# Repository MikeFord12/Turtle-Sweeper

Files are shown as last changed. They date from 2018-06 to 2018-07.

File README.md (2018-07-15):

# Turtle-Sweeper

# Background

This repository holds the code for the turtle sweeper team's GVSU final project. Code for each module, libraries, and then main logic code are included.

The purpose of this project is to provide a solution for tracking neonate (newborn) turtles in their natural wooded habitat that is more cost-effective than the current method. RFID technology can provide an inexpensive option to do this. The low cost of the tags will enable more neonates to be tracked at once, which given their high mortality rate, will provide better data on their migratory habits. RFID was also chosen due to the availability of long-lasting tags. Passive RFID tags can last years, while active VHF tags run out of battery life in about a month.

The goal is to design an easy to use system that can easily find and identify turtles, as well as keep track of their movement through seamless data logging. In order to be able to easily identify the turtles in the wild the Ultra High-Frequency range was chosen due to its longer read ranges. An Arduino Mega 2560 was selected as the microcontroller interface with the ThingMagic M6E Nano reader shield. To achieve higher gain and external antenna was added.  A 6mm passive RFID tag was selected, and based on Fiis Transmission estimations, the tag will read at the 10” ranges in free space and in dry conditions.

The UI was designed using modules compatible with the Arduino microcontroller to include event saving functionality, GPS location, LCD display, battery level indication, and keeping time. The mechanical design was inspired by a metal detector wand. The metal detector design will increase the reach of the user and place the antenna closer to the specimen. Overall this design will improve the ability to control the antenna and improve its portability. The increased portability will enable the user to cover more ground and search in areas that might be difficult to reach. 

# Setup

If anyone desires to clone and run this code, the included libraries must be present in the user’s Arduino IDE. The Arduino IDE used for development is Version 1.8.5. The SD, SoftwareSerial, and SPI libraries used are included in the Arduino IDE. The external libraries used are included in the Github repo. 

---------------------------------------------------------------------
**In order for these to work you must put these library folders in your “arduino->libraries” directory. If there is no libraries folder in your arduino directory, you must create one and put the library folders inside of there.**
---------------------------------------------------------------------

# Contact

For questions about this repository you can contact:  
Mike Ford – fordmich@mail.gvsu.edu  
David Bizzocchi – bizzoccd@mail.gvsu.edu

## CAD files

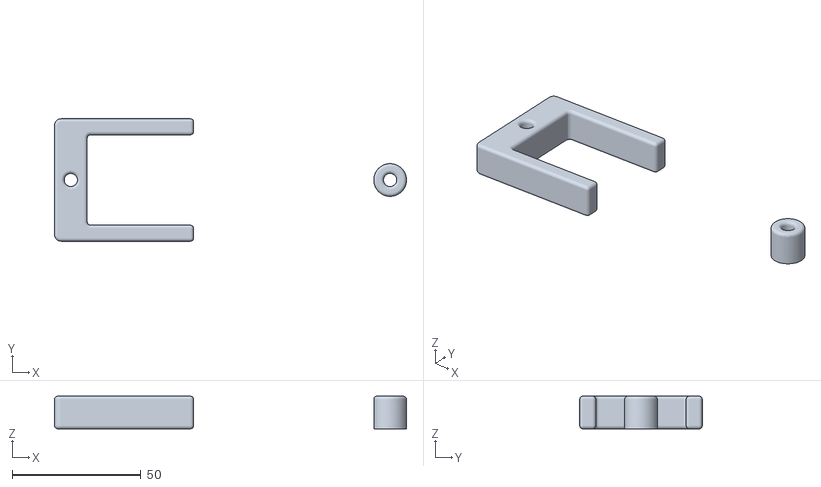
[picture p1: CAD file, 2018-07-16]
3D prints/Battery Holder Size Reducer.STL
136.5 x 47.5 x 12.7

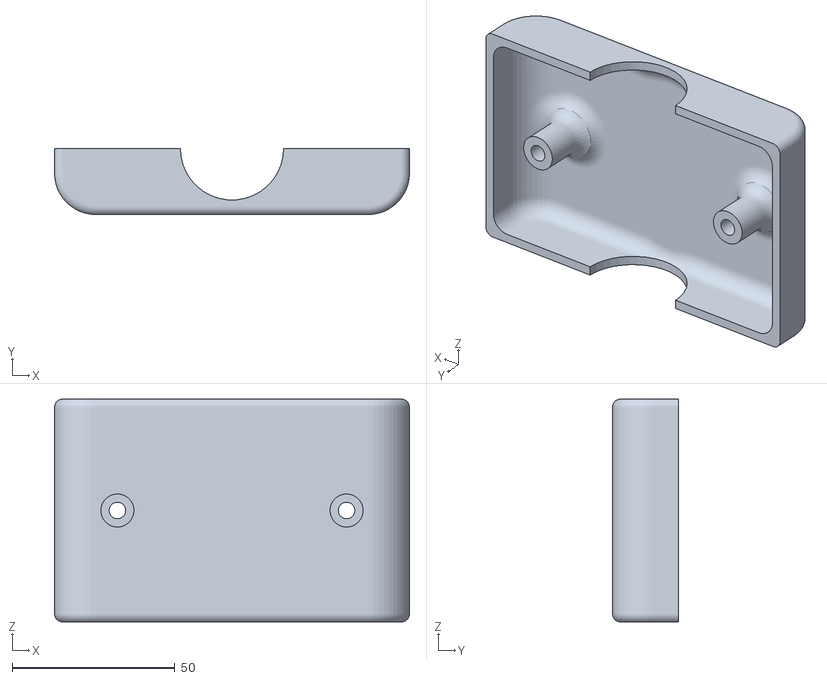
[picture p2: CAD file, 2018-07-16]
3D prints/Bracket_CASE_COVER.STL
109.2 x 20.3 x 68.6

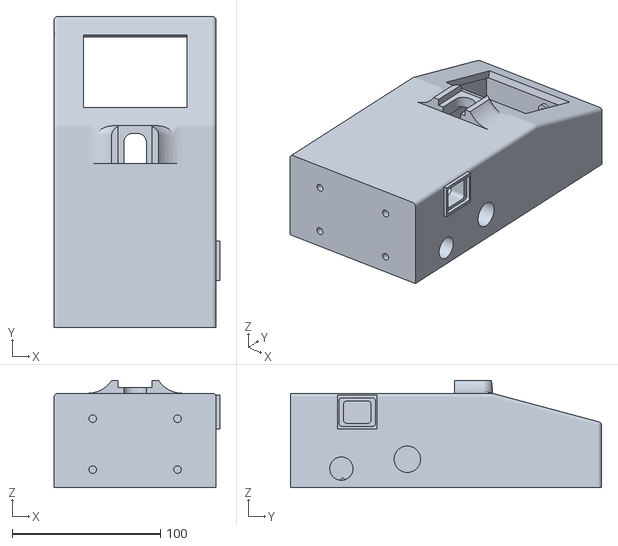
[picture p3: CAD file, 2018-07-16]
3D prints/Handle_V3_SIDE_A.STL
111.8 x 209.6 x 72.1

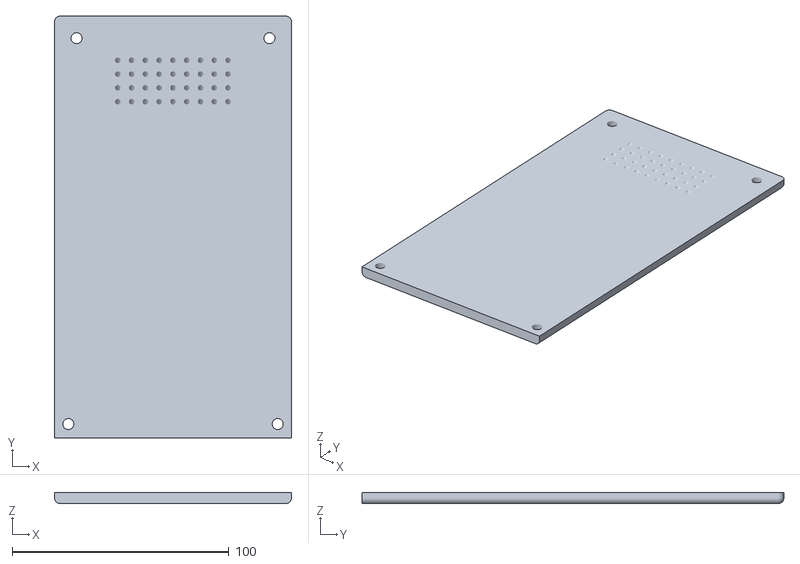
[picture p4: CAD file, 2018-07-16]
3D prints/LCD_BackPlate_V3.STL
109.2 x 194.3 x 5.08

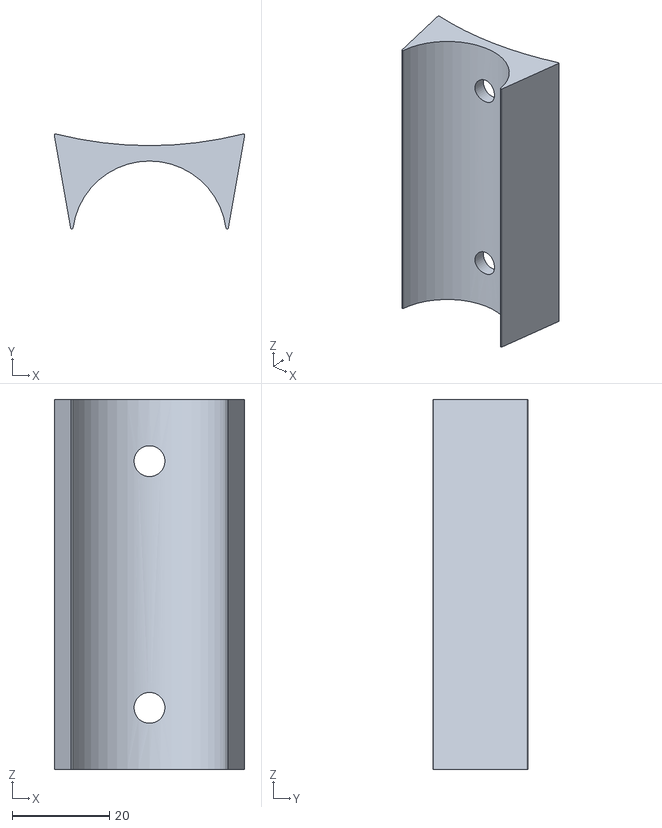
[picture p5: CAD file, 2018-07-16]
3D prints/ArmRest_Adpt.STL
39.2 x 19.6 x 76.2

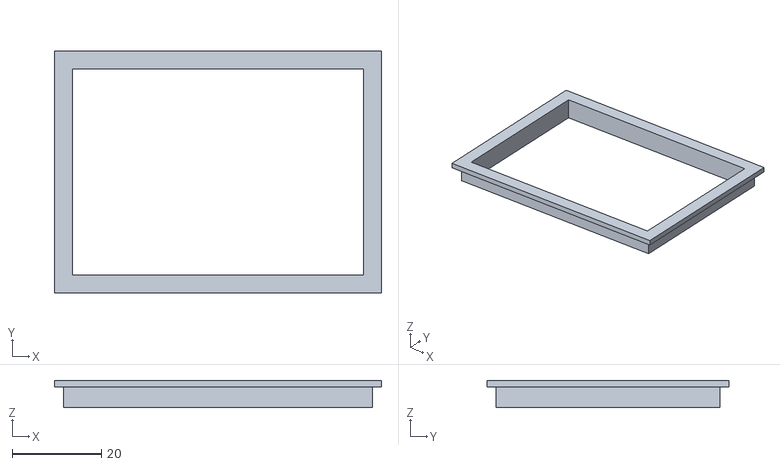
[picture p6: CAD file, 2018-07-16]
3D prints/LCD Screen Gasket.STL
73.5 x 54.3 x 6.07

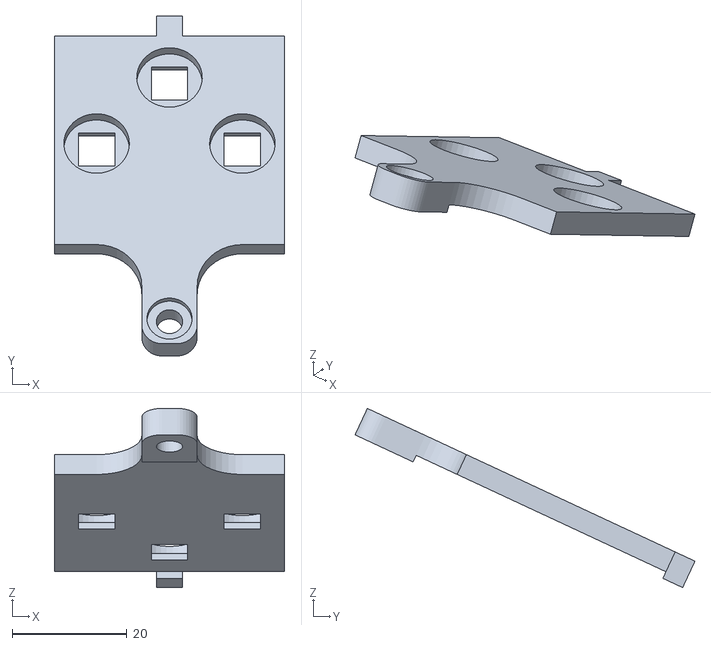
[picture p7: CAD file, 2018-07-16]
3D prints/Handle_V3_SIDE_B_LARGE_BUTTON_COVER.STL
40.1 x 59.2 x 31.2

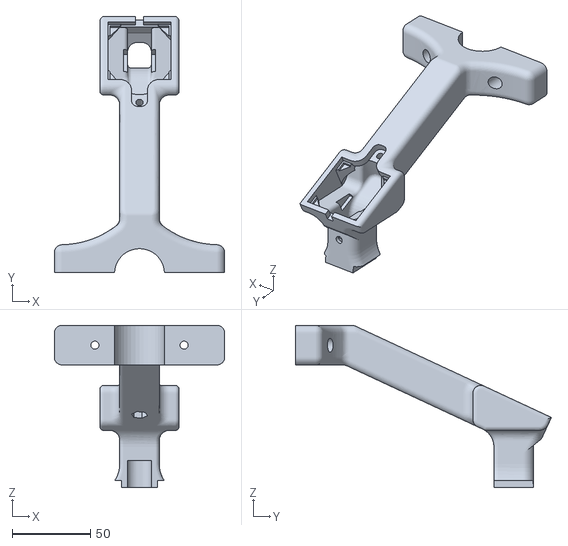
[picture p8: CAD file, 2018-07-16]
3D prints/Handle_V3_SIDE_B_LARGE_BUTTON.STL
109.2 x 164.0 x 104.0

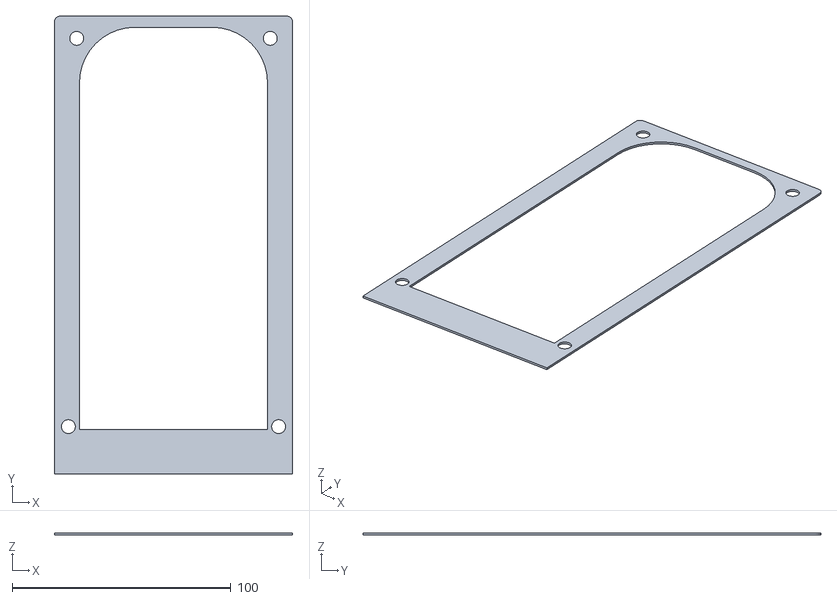
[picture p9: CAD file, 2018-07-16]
3D prints/Handle Case Gasket.STL
108.8 x 209.3 x 1.00

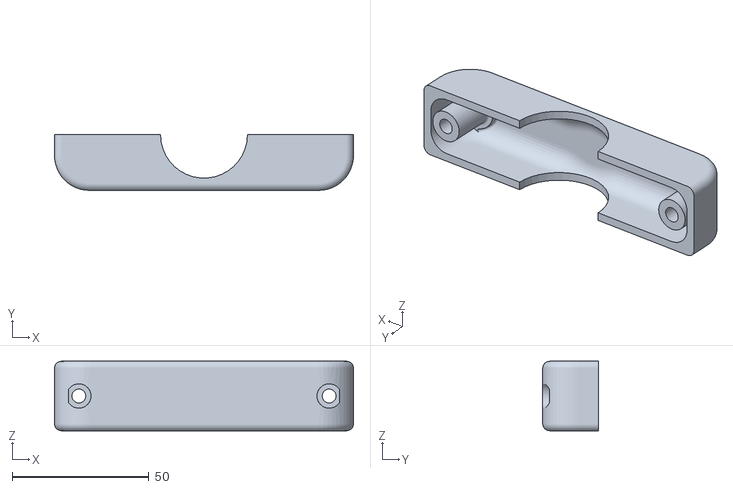
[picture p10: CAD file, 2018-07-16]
3D prints/Bracket_HANDLE_COVER.STL
109.2 x 20.3 x 25.4

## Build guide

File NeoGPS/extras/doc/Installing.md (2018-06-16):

Installing
==========

1. [Download the library](#1-download-the-library)
2. [Choose a serial port](#2-choose-a-serial-port)
3. [Connect the GPS device](#3-connect-the-gps-device)
4. [Review `GPSport.h`](#4-review-librariesneogpssrcgpsporth)
5. [Open the example](#5--open-the-example-sketch-nmeaino)
6. [Build and upload](#6--build-and-upload-the-sketch-to-your-arduino)
<hr>

### 1. Download the library

It is easiest to use the [Ardino IDE Library Manager](https://www.arduino.cc/en/Guide/Libraries#toc3) to automatically download and install NeoGPS.  Select the menu **Sketch -> Include Library -> Manage Libraries**.  Then type "NeoGPS" in the Search box.

If you need to perform a manual installation,:

* Download the [master ZIP file](https://github.com/SlashDevin/NeoGPS/archive/master.zip).
*  Open the zip file and open the nested `NeoGPS-master` subdirectory.
*  Select and copy all files in the `NeoGPS-master` subdirectory into a new `Arduino/Libraries/NeoGPS` directory, like most libraries.  The `Arduino/Libraries/NeoGPS` directory should contain:<br>
```
extras
examples
src
library.properties
LICENSE
README.md
```

<hr>

### 2. Choose a serial port

**BEST**: The fastest, most reliable way to connect a GPS device is to use a HardwareSerial port.

On any Arduino board, you can connect the GPS device to the `Serial` pins (0 & 1).  You can still print debug statements, and they will show up on the Serial Monitor window.  The received GPS characters will not interfere with those prints, and you will not see those characters on the Serial Monitor window.

However, when you need to upload a new sketch to the Arduino over USB, **you must disconnect the GPS TX from the Arduino RX pin 0.**  Otherwise, the GPS characters will interfere with the upload data.  Some people put a switch in that connection to make it easy to upload without disturbing the wires.

For Mega, Due and Teensy boards, you can connect the GPS device to the `Serial1`,  `Serial2` or `Serial3` pins.

For Micro and Leo (and other 32U4-based Arduinos), you can connect the GPS device to the `Serial1` pins.

**2nd Best**:  If you can't connect the GPS device to a `HardwareSerial` port, you should download and install the [AltSoftSerial](https://github.com/PaulStoffregen/AltSoftSerial) or [NeoICSerial](https://github.com/SlashDevin/NeoICSerial) library.  These libraries only work on two specific pins (8 & 9 on an UNO).  This library is very efficient and reliable.  It uses one of the hardware TIMERs, so it may conflict with libraries that use TIMERs or PWM output (e.g., servo).

**3rd Best**:  If you can't use the pins required by `AltSoftSerial`, and your GPS device runs at 9600, 19200 or 38400 baud, you should download and install the [NeoSWSerial](https://github.com/SlashDevin/NeoSWSerial) library.  This library is almost as efficient.  It will help you avoid common timing problems caused by `SoftwareSerial`.  It does not need an extra TIMER, so it can be used with most other libraries.  It does use Pin Change Interrupts, but there is an option in the header file that allows you to coordinate other PCI usage with `NeoSWSerial`.

`NeoSWSerial` can be used with `AltSoftSerial` at the same time, allowing your sketch to have two extra serial ports.

**WORST**:  `SoftwareSerial` is NOT RECOMMENDED, because it disables interrupts for long periods of time.  This can interfere with other parts of your sketch, or with other libraries.  It cannot transmit and receive at the same time, and your sketch can only receive from one `SoftwareSerial` instance at time.

<hr>

### 3. Connect the GPS device

Most GPS devices are 3.3V devices, and most Arduinos are 5V devices.  Although many GPS modules are described as "3V & 5V compatible", 

<p align=center><b>YOU SHOULD NOT CONNECT A 5V ARDUINO TRANSMIT PIN TO THE 3.3V GPS RX PIN</b></p>

This can damage the device, cause overheating, system power problems or decrease the lifetime of battery-operated systems.  You must level-shift this connection with inexpensive level-shifting modules (best) or a resistor divider.

Connecting the 3.3V GPS TX pin to a 5V Arduino receive pin will not damage the GPS device, but it may not be reliable.  This is because the GPS TX voltage is slightly lower than what the Arduino requires.  It works in many situations, but if you are not able to receive GPS characters reliably, you probably need to use a level-shifting module (best) or a diode+resistor to "pull up" the GPS TX pin voltage.

<hr>

### 4. Review `Libraries/NeoGPS/src/GPSport.h`

This file declares a the serial port to be used for the GPS device.  You can either:

* Use the default `GPSport.h` and connect your GPS device according to what it chooses; or
* Replace the entire contents of `GPSport.h` and insert your own declarations (see below and comments in `GPSport.h`).

#### Default choices for GPSport.h

By default, Mega, Leonardo, Due, Zero/MKR1000 and Teensy boards will use `Serial1`.

All other Boards will use [AltSoftSerial](https://github.com/PaulStoffregen/AltSoftSerial) on two specific pins (see table at linked page).

If you want to use a different serial port library (review step 2 above), you must edit these `#include` lines in `GPSport.h`:

```
  //#include <NeoHWSerial.h>    // NeoSerial or NeoSerial1 for INTERRUPT_PROCESSING
  #include <AltSoftSerial.h>    // <-- DEFAULT.  Two specific pins required (see docs)
  //#include <NeoICSerial.h>    // AltSoftSerial with Interrupt-style processing
  //#include <NeoSWSerial.h>    // Any pins, only @ 9600, 19200 or 38400 baud
  //#include <SoftwareSerial.h> // NOT RECOMMENDED!
```

Uncomment **one** of those include statements, and it will use that library for the GPS serial port.

If you uncomment the `NeoSWSerial.h` include, pins 3 and 4 will be used for the GPS.  If your GPS is on different pins, you must edit these `#define` lines in `GPSport.h`:

    #define RX_PIN 4
    #define TX_PIN 3

#### Choosing your own serial port

If you know what serial port you want to use, you can **REPLACE EVERYTHING** in `GPSport.h' with the three declarations that are used by all example programs: 

1. the `gpsPort` variable **(include its library header if needed)**;
2. the double-quoted C string for the `GPS_PORT_NAME` (displayed by all example programs); and
3. the `DEBUG_PORT` to use for Serial Monitor print messages (usually `Serial`).

All the example programs can use any of the following serial port types:

* HardwareSerial (built-in `Serial`, `Serial1` et al. STRONGLY recommended)
* [AltSoftSerial](https://github.com/PaulStoffregen/AltSoftSerial) **DEFAULT** (only works on one specific Input Capture pin)
* [NeoICSerial](https://github.com/SlashDevin/NeoICSerial) (only works on one specific Input Capture pin)
* [NeoHWSerial](https://github.com/SlashDevin/NeoHWSerial) (required for NMEA_isr and NMEASDlog on built-in serial ports)
* [NeoSWSerial](https://github.com/SlashDevin/NeoSWSerial) (works on most pins)
* SoftwareSerial (built-in, NOT recommended)

Be sure to download the library you have selected (NOTE: `HardwareSerial` and `SoftwareSerial` are pre-installed by the Arduino IDE and do not need to be downloaded).

For example, to make all examples use `Serial` for the GPS port **and** for Serial Monitor messages, `GPSport.h` should contain just these 3 declarations:

```
#ifndef GPSport_h
#define GPSport_h

#define gpsPort Serial
#define GPS_PORT_NAME "Serial"
#define DEBUG_PORT Serial

#endif
```

Or, to make all examples use `AltSoftSerial` for the GPS port and `Serial` for Serial Monitor messages, `GPSport.h` should contain just these statements:

```
#ifndef GPSport_h
#define GPSport_h

#include <AltSoftSerial.h>
AltSoftSerial gpsPort;
#define GPS_PORT_NAME "AltSoftSerial"
#define DEBUG_PORT Serial

#endif
```

<hr>

### 5.  Open the example sketch NMEA.ino

In the Arduino IDE, select **File -> Examples -> NeoGPS -> NMEA**.

<hr>

### 6.  Build and upload the sketch to your Arduino.

**Note:**  If the sketch does not compile, please see the [Troubleshooting](Troubleshooting.md#configuration-errors) section.

When the sketch begins, you should see this:
```
NMEA.INO: started
  fix object size = 31
  gps object size = 84
Looking for GPS device on Serial1

GPS quiet time is assumed to begin after a RMC sentence is received.
  You should confirm this with NMEAorder.ino

Status,UTC Date/Time,Lat,Lon,Hdg,Spd,Alt,Sats,Rx ok,Rx err,Rx chars,
3,2016-05-24 01:21:29.00,472852332,85652650,,138,,,1,0,66,
3,2016-05-24 01:21:30.00,472852311,85652653,,220,24040,7,9,0,557,
3,2016-05-24 01:21:31.00,472852315,85652647,,449,24080,7,17,0,1048,
  etc.
```
The default NeoGPS configuration is **Nominal**, as described [here](Configurations.md#typical-configurations).  If you do not see this output, please review the  [Troubleshooting](Troubleshooting.md#gps-device-connection-problems) section.

This output can be copy & pasted into a into a text editor for saving as a CSV file, which can then be imported into a spreadsheet program for graphing or analysis.

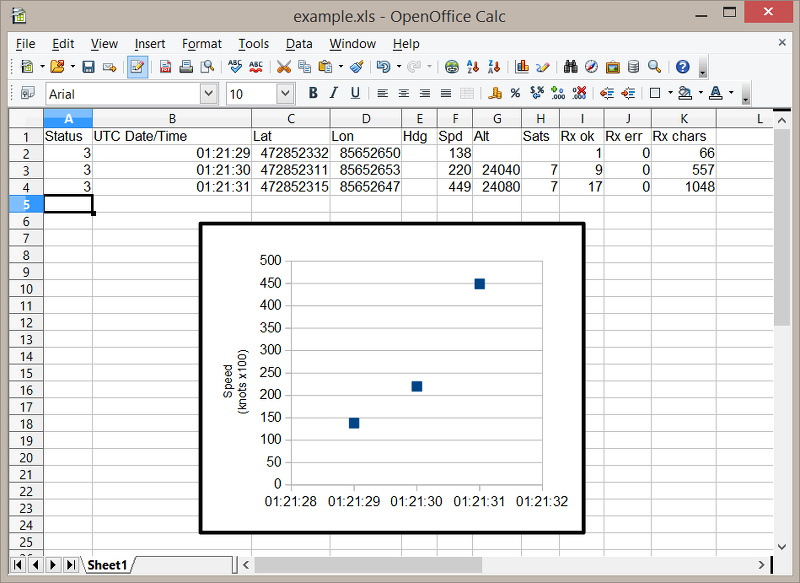
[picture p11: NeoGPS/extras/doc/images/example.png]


<hr>

### The NMEA.ino example works!
Once you have verified the GPS device connection and build process with this first example, you should also verify your device's behavior with `NMEAorder.ino` (see [this section](Troubleshooting.md#quiet-time-interval)).  This can avoid problems later on, when you start adding/merging other functions to do your "work".

[Other examples](Examples.md) include `NMEAloc.ino`, which shows how to use just the location fields of a fix, or `NMEAtimezone.ino`, which shows how to adjust the GPS time for your local time zone.

If you are logging information to an SD card, you should next try `NMEA_isr.ino`.  It is identical to `NMEA.ino`, except that it handles the GPS characters during the RX char interrupt.  Interrupt handling will require one of the NeoXXSerial libraries to be installed (e.g. [NeoHWSerial](https://github.com/SlashDevin/NeoHWSerial)).

If you are working on a drone or other autonomous system, you should read about [Coherency](Coherency.md) and the interrupt-driven technique in [NMEA_isr](/examples/NMEA_isr/NMEA_isr.ino).

You can also try other configurations.  Please see [Choosing Your Configuration](Choosing.md) for more information, and then simply edit `GPSfix_cfg.h` and/or `NMEAGPS_cfg.h`, or select an [example configuration](../configs) and copy these three files into your application directory: `NeoGPS_cfg.h`, `GPSfix_cfg.h`, and `NMEAGPS_cfg.h`.

You can review and edit each of the copied configuration files to add or remove messages or fields, at any time.

**Note:**  Not all configurations will work with all example applications.  Compiler error messages are emitted for incompatible settings, or if an example requires certain configurations.

### I have a ublox GPS device
After you have tried all the standard NMEA examples, and you need the ublox-specific capabilities of NeoGPS, please see the [ublox](ublox.md) section.  Try `PUBX.ino` first, then try `ublox.ino` if you *really* need the binary protocol.

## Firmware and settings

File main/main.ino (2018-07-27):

#include <SparkFun_UHF_RFID_Reader.h>
#include <Buzzer.h>
#include <RFID_Drivers.h>
#include <SoftwareSerial.h>
#include <PushButtons.h>
#include <SPI.h>
#include <SD.h>
#include <NeoHWSerial.h>
#include <NeoHWSerial_private.h>
#include <NMEAGPS.h>
#include <LEDs.h>
#include <GPS.h>
#include <VoltageReader.h>
#include "Globals.h"
#include <LCD.h>
#include <SD_Drivers.h>
#include "Adafruit_GFX.h"
#include "Adafruit_ILI9341.h"

//GPS object and fix object
NMEAGPS gps;
gps_fix fix;

//log of turtles found
char tagIDS[20][50];
int turtlesFound = 0;

//RFID object
RFID nano;
SoftwareSerial softSerial(12, 13); //RX, TX

//time tracking variables for updating time and checking batteries
unsigned long previousBatteryCheckTime = 0;
int tenMinuteBatterySplashscreen = 0;

//Timeout for waiting for GPS fix
unsigned long GPS_FIX_TIMEOUT = 0;
unsigned long GPS_GATHERING_DATA_TIMEOUT = 0;
int GPS_GATHERING_TIMEOUT = 0;

// LED toggling variables
unsigned long TOGGLE_LED_TIMER = 0;
int LED_TOGGLE = 1;

// Variable for no select button timeout
unsigned long BUTTON_SELECT_TIMEOUT = 0;

//Variables for GPS and SD initialization
int SD_INITIALIZED_CORRECTLY = 1;
int GPS_INITIALIZED_CORRECTLY = 1;

// variable to keep track of which button press
int buttonSelect = BUTTON_NONE;

// variable to determine which mode the system is in
int isInReadingMode = 0;

// current voltage
double voltage;

//Program state variable
//STATE can be GPS_FIX, MAIN_SCREEN, or DETECTION_SCREEN
int STATE;

//display object
Adafruit_ILI9341 tft = Adafruit_ILI9341(TFT_CS, TFT_DC, TFT_RST);

//Data file object
File myFile;

//Number to write to tag
int tagIDToWrite = 0;

void setup() {
  //Serial port to print out debug messages
  NeoSerial.begin(115200);
  while (!NeoSerial);

  //code for status failures
  int statusCode = 0;

  //initialize LCD and Buttons for mode selection
  setupLCD();

  //NeoSerial.println("LCD initalized");

  setupPushButtons();
  //NeoSerial.println("Buttons initalized");

  // Ask user for read/write mode
  drawModeSelectScreen();

  // Loop until select button is pressed
  while ((buttonSelect = buttonPressed()) != BUTTON_SELECT)
  {
    // Draw selection based on user input
    switch (buttonSelect)
    {
      case (BUTTON_LEFT):
      NeoSerial.println("LEFT BUTTON PUSHED");
        drawYesSelection();
        break;
      case (BUTTON_RIGHT):
      NeoSerial.println("RIGHT BUTTON PUSHED");
        drawNoSelection();
        break;
    }
  }

  // Set mode variable based on user input
  if (optionSelected() == YES_SELECTED)
  {
    isInReadingMode = 1;
  }
  else
  {
    isInReadingMode = 0;
  }

  if (isInReadingMode)
  {
    //Initialize RFID Reader, LCD, GPS, LEDS, buzzer, SD
    setupLEDS();
    //NeoSerial.println("LEDS initalized");
    setupGPS();
    //NeoSerial.println("GPS initalized");


    if (statusCode = setupCommunication())
    {
      drawErrorScreen(statusCode);
      while (1);
    }
    else
    {
      NeoSerial.println("RFID initalized");
    }

    setupBuzzer();
    NeoSerial.println("Buzzer initialized");

    if (statusCode = initializeSDCard())
    {
      //If SD is not initialized correctly
      SD_INITIALIZED_CORRECTLY = 0;
      drawErrorScreen(statusCode);
      delay(1000);
    }
    else
    {
      NeoSerial.println("SD initalized");
    }
    //If battery is very low on powerup, display low battery and do not let the system go further until they replace or recharge battery
    if (getBatteryTimeRemaining() <= 5)
    {
      drawCriticalBatteryScreen();
      while (1);
    }

    STATE = GPSFIX_SCREEN;

    //Stay in while until we get a valid GPS fix
    drawInitializationScreen();
    GPS_FIX_TIMEOUT = millis();
    while (STATE == GPSFIX_SCREEN)
    {
      if (gps.available())
      {
        //Read Fix
        fix = gps.read();

        if (fix.valid.time && fix.valid.location)
        {
          STATE = MAIN_SCREEN;
        }
      }
      //If we have waited 6 minutes and there is still no fix, disable GPS and logging functionality
      if (millis() - GPS_FIX_TIMEOUT > SIX_MINUTES_IN_MS || (buttonPressed() == BUTTON_SELECT))
      {
        GPS_INITIALIZED_CORRECTLY = 0;
        STATE = MAIN_SCREEN;
      }
    }
  }
  else if (!isInReadingMode)
  {
    if (statusCode = setupCommunicationWriteMode())
    {
      drawErrorScreen(statusCode);
      while (1);
    }
  }
}

void loop() {


  if (isInReadingMode)
  {
    //code if system is in main state
    if (STATE == MAIN_SCREEN)
    {
      //reset turtle already logged
      int turtleAlreadyLogged = 0;

      //display green LED and draw main screen
      displayGreen();
      drawMainScreen(GPS_INITIALIZED_CORRECTLY, SD_INITIALIZED_CORRECTLY);
      drawTurtlesFound(turtlesFound);
      writeCharge(getBatteryTimeRemaining());

      //if gps fix is available, read it in
      if (GPS_INITIALIZED_CORRECTLY)
      {
        if (gps.available())
        {
          //Read Fix
          fix = gps.read();
        }
      }

      //Begin scanning for tags
      nano.startReading();

      // Loop through read stages
      while (STATE == MAIN_SCREEN)
      {
        char myEPC[50] = "";

        if (LED_TOGGLE)
        {
          displayGreen();
        }
        else
        {
          turnOff();
        }

        // Toggle LED timer when needed
        if (millis() - TOGGLE_LED_TIMER >= TWO_SECONDS_IN_MS)
        {
          //update new battery check time
          TOGGLE_LED_TIMER = millis();

          //check battery charge
          LED_TOGGLE = !LED_TOGGLE;
        }


        //If we havent checked the battery charge in over 10 minutes
        if (millis() - previousBatteryCheckTime >= ONE_MINUTE_IN_MS)
        {
          //update new battery check time
          previousBatteryCheckTime = millis();

          //check battery charge
          writeCharge(getBatteryTimeRemaining());
        }

        if (getBatteryTimeRemaining() <= 5)
        {
          nano.stopReading();
          drawCriticalBatteryScreen();
          while (1);
        }

        /*  if (getBatteryTimeRemaining() <= 10 && !tenMinuteBatterySplashscreen)
          {
            tenMinuteBatterySplashscreen = 1;
            tenMinuteSplashScreen();

              displayGreen();
          drawMainScreen(GPS_INITIALIZED_CORRECTLY, SD_INITIALIZED_CORRECTLY);
          drawTurtlesFound(turtlesFound);
          writeCharge(getBatteryTimeRemaining());
          }*/

        //if gps fix is available, read it in
        if (GPS_INITIALIZED_CORRECTLY)
        {
          if (gps.available())
          {
            //Read Fix
            fix = gps.read();
          }
        }

        //Loop checking for high signal from RFID reader
        if (nano.check() == true) //Check to see if any new data has come in from module
        {

          byte responseType = nano.parseResponse(); //Break response into tag ID, RSSI, frequency, and timestamp

          //only check if we found a tag, dont care about anything else
          if (responseType == RESPONSE_IS_TAGFOUND)
          {
            //sound buzzer is tag found
            soundBuzzer();

            byte tagEPCBytes = nano.getTagEPCBytes(); //Get the number of bytes of EPC from response
            //Print EPC bytes, this is a subsection of bytes from the response/msg array
            for (byte x = 0 ; x < tagEPCBytes ; x++)
            {
              char arrayByte[3];

              if (nano.msg[31 + x] < 0x10)
              {
                strcat(myEPC, "0"); //Pretty print
              }
              //convert int to char array
              itoa (nano.msg[31 + x], arrayByte, 10);
              //add it to the end of our ID char array
              strcat(myEPC, arrayByte);

              strcat(myEPC, " ");
            }
            //NeoSerial.println(myEPC);

            //See if we already found tag
            for (int i = 0; i < turtlesFound; i++)
            {
              if (!strcmp(myEPC, tagIDS[i]))
              {
                //if we have, done treat it as a new detection event
                turtleAlreadyLogged = 1;
                break;
              }
            }
            //If tag found for the first time
            if (!turtleAlreadyLogged)
            {
              //If GPS is working, go to detection state
              //If not, no point in going as we cant get coordinates or timestamp
              if (GPS_INITIALIZED_CORRECTLY)
              {
                STATE = DETECTION_SCREEN;
              }
              //add turtle to log
              strcpy(tagIDS[turtlesFound] , myEPC);

              //if neither initialized, show user the tag found, user must press select to advance
              if (!GPS_INITIALIZED_CORRECTLY && !SD_INITIALIZED_CORRECTLY)
              {
                displayRed();
                drawBasicDetectionScreen(myEPC);
                BUTTON_SELECT_TIMEOUT = millis();
                while ((buttonSelect = buttonPressed() == BUTTON_NONE) && (millis() - BUTTON_SELECT_TIMEOUT < BUTTON_TIMEOUT));

                drawMainScreen(GPS_INITIALIZED_CORRECTLY, SD_INITIALIZED_CORRECTLY);
                writeCharge(getBatteryTimeRemaining());
              }

              //if no GPS but there is SD, log the tag ID found
              if (!GPS_INITIALIZED_CORRECTLY && SD_INITIALIZED_CORRECTLY)
              {
                displayRed();
                drawBasicDetectionScreen(myEPC);
                BUTTON_SELECT_TIMEOUT = millis();
                while ((buttonSelect = buttonPressed() == BUTTON_NONE) && (millis() - BUTTON_SELECT_TIMEOUT < BUTTON_TIMEOUT));
                logDetectionEvent(myEPC, "GPS Data Timeout", "GPS Data Timeout", 1234567, 1234567);
                drawMainScreen(GPS_INITIALIZED_CORRECTLY, SD_INITIALIZED_CORRECTLY);
                writeCharge(getBatteryTimeRemaining());
              }

              //update number of turtles found
              turtlesFound++;
              drawTurtlesFound(turtlesFound);
            }
            //reset flag
            turtleAlreadyLogged = 0;
          }
        }
      }
    }

    //code if turtle found
    if (STATE == DETECTION_SCREEN)
    {
      //NeoSerial.println("Detection state");
      //initilize detection event structure
      detectionEventInfo detectionEvent;
      char timeStamp[25];
      char dateString[25];
      float detectionScreenLong = 0;
      float detectionScreenLat = 0;

      char epcFound[50] = "";

      //Turn LED RED
      displayRed();
      //sound buzzer
      soundBuzzer();

      //set tag ID into struct
      strcpy(detectionEvent.tagID , tagIDS[turtlesFound - 1]);
      sprintf(epcFound, "ID: %s", detectionEvent.tagID);

      //Wait for next GPS input and parse time and coordinates out and save to detectionEvent struct
      gatheringGPSScreen();

      if (!fix.valid.location || !fix.valid.time || !fix.valid.date)
      {
        while (!gps.available());
        fix = gps.read();
        GPS_GATHERING_DATA_TIMEOUT = millis();
        //wait until we have valid data from GPS to save
        while (!fix.valid.location || !fix.valid.time || !fix.valid.date)
        {
          if (gps.available())
          {
            //Read Fix
            fix = gps.read();
          }
          if ((millis() - GPS_GATHERING_DATA_TIMEOUT) >= THIRTY_SECONDS_IN_MS)
          {
            GPS_GATHERING_TIMEOUT = 1;
            break;
          }
        }
      }

      //If location vaild
      if (fix.valid.location)
      {
        detectionEvent.latitude = fix.latitudeL();
        detectionEvent.longitude = fix.longitudeL();

        detectionScreenLong = (detectionEvent.longitude) / (10000000.00);
        detectionScreenLat = (detectionEvent.latitude) / (10000000.00);
      }

      if (fix.valid.time && fix.valid.date)
      {
        //Adjust time to EST
        adjustTime(fix.dateTime);
        //Convert from military time to conventional
        fix.dateTime.setAMorPM();

        //Format date string and save
        sprintf(timeStamp, "%d:%02d:%02d %02d-%02d-%d", fix.dateTime.hours, fix.dateTime.minutes, fix.dateTime.seconds, fix.dateTime.month, fix.dateTime.date, fix.dateTime.year);
        sprintf(detectionEvent.timeS, "%d:%02d:%02d", fix.dateTime.hours, fix.dateTime.minutes, fix.dateTime.seconds);
        sprintf(detectionEvent.dateS, "%02d-%02d-%d", fix.dateTime.month, fix.dateTime.date, fix.dateTime.year);
        sprintf(dateString, "Time: %s", timeStamp);
      }

      if (!GPS_GATHERING_TIMEOUT)
      {
        //After data collection, Draw Screen
        drawDetectionScreen(epcFound, dateString, detectionScreenLong, detectionScreenLat);
      }
      else
      {
        drawDetectionScreen(epcFound, "GPS Data Timout", 00.000, 00.000);
      }


      //Set button timeout variable
      BUTTON_SELECT_TIMEOUT = millis();

      //Wait for either Yes or no to log data (check input push buttons)
      //Timeout after set time of no button pressed
      while (((buttonSelect = buttonPressed() != BUTTON_SELECT)) &&
             (millis() - BUTTON_SELECT_TIMEOUT < BUTTON_TIMEOUT))
      {
        switch (buttonSelect)
        {
          case (BUTTON_LEFT):
            drawYesSelection();
            break;
          case (BUTTON_RIGHT):
            drawNoSelection();
            break;
        }
      }

      //IF yes is selected and timeout is not met, log data and display on UI
      if ((optionSelected() == YES_SELECTED))
      {
        //If Yes and SD card initialized correctly: Log to SD card
        if (SD_INITIALIZED_CORRECTLY)
        {
          if (!GPS_GATHERING_TIMEOUT)
          {
            if (!(logDetectionEvent(detectionEvent.tagID, detectionEvent.timeS, detectionEvent.dateS, detectionEvent.latitude, detectionEvent.longitude)))
            {
              DEBUG_PORT.println("Error logging to SD Card");
            }
          }
          else
          {
            if (!(logDetectionEvent(detectionEvent.tagID, "GPS Data Timout", "GPS Data Timout", 1234567, 1234567)))
            {
              DEBUG_PORT.println("Error logging to SD Card");
            }
            GPS_GATHERING_TIMEOUT = 0;
          }
        }
        STATE = MAIN_SCREEN;
      }
      else
      {
        //If No: Go back to MAIN_SCREEN state
        STATE = MAIN_SCREEN;
      }
    }
  }

  // code for write mode
  else if (!isInReadingMode)
  {
    // reset write variable ID
    tagIDToWrite = 0;

    // Display user input screen
    drawNumberScreen();

    printDesiredTagValue(tagIDToWrite); //shows 0 on screen

    // loop until button select is pressed
    while ((buttonSelect = buttonPressed()) != BUTTON_SELECT)
    {
       //decrement variable and value shown on screen
      if ((buttonSelect == BUTTON_LEFT) && tagIDToWrite > 0)
      {
        tagIDToWrite--;
        printDesiredTagValue(tagIDToWrite);
      }

      //increment variable and value shown on screen
      if ((buttonSelect == BUTTON_RIGHT) && tagIDToWrite < 255)
      {
        tagIDToWrite++;
        printDesiredTagValue(tagIDToWrite);
      }
    }

    //display are you sure screen
    writeConfirmationScreen(tagIDToWrite);

    // Prompt user for selection ensure
    while ((buttonSelect = buttonPressed()) != BUTTON_SELECT)
    {
      switch (buttonSelect)
      {
        case (BUTTON_LEFT):
          drawYesSelection();
          break;
        case (BUTTON_RIGHT):
          drawNoSelection();
          break;
      }
    }

    // If user selected yes
    if (optionSelected() == YES_SELECTED)
    {
      if (writeToTag(tagIDToWrite))
      {
        //display tag successful screen, do you want to write another tag
        drawWriteSuccessful();
      }
      else
      {
        //display tag not written successfully do you want to try again
        drawWriteFailure();
      }
    }
    // If user selected no
    else
    {
      isInReadingMode = 0;
    }
  }
}

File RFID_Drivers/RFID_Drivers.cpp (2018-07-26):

#include "RFID_Drivers.h"

//Gracefully handles a reader that is already configured and already reading continuously
//Because Stream does not have a .begin() we have to do this outside the library
boolean setupNano(long baudRate)
{
        nano.begin(softSerial); //Tell the library to communicate over software serial port

        //Test to see if we are already connected to a module
        //This would be the case if the Arduino has been reprogrammed and the module has stayed powered
        softSerial.begin(baudRate); //For this test, assume module is already at our desired baud rate
        while(!softSerial); //Wait for port to open

        //About 200ms from power on the module will send its firmware version at 115200. We need to ignore this.
        while(softSerial.available()) softSerial.read();

        nano.getVersion();

        if (nano.msg[0] == ERROR_WRONG_OPCODE_RESPONSE)
        {
                //This happens if the baud rate is correct but the module is doing a ccontinuous read
                nano.stopReading();

                NeoSerial.println(F("Module continuously reading. Asking it to stop..."));

                delay(1500);
        }
        else
        {
                //The module did not respond so assume it's just been powered on and communicating at 115200bps
                softSerial.begin(115200); //Start software serial at 115200

                nano.setBaud(baudRate); //Tell the module to go to the chosen baud rate. Ignore the response msg

                softSerial.begin(baudRate); //Start the software serial port, this time at user's chosen baud rate
        }

        //Test the connection
        nano.getVersion();
        if (nano.msg[0] != ALL_GOOD) return (false); //Something is not right

        //The M6E has these settings no matter what
        nano.setTagProtocol(); //Set protocol to GEN2

        nano.setAntennaPort(); //Set TX/RX antenna ports to 1

        return (true); //We are ready to rock
}

int setupCommunication()
{
        NeoSerial.begin(115200);
        while (!NeoSerial); //Wait for the serial port to come online

        if (setupNano(38400) == false) //Configure nano to run at 38400bps
        {
                NeoSerial.println(F("Module failed to respond. Please check wiring."));
                return 2;
        }

        nano.setRegion(REGION_NORTHAMERICA); //Set to North America

        nano.setReadPower(2700); //5.00 dBm. Higher values may caues USB port to brown out
        //Max Read TX Power is 27.00 dBm and may cause temperature-limit throttling

        return 0;
}

int setupCommunicationWriteMode()
{
        NeoSerial.begin(115200);
        while (!NeoSerial); //Wait for the serial port to come online

        if (setupNano(38400) == false) //Configure nano to run at 38400bps
        {
                NeoSerial.println(F("Module failed to respond. Please check wiring."));
                return 2;
        }

        nano.setRegion(REGION_NORTHAMERICA); //Set to North America

        nano.setReadPower(2700); //5.00 dBm. Higher values may caues USB port to brown out
        //Max Read TX Power is 27.00 dBm and may cause temperature-limit throttling

        nano.setWritePower(2700); //5.00 dBm. Higher values may caues USB port to brown out
        //Max Read TX Power is 27.00 dBm and may cause temperature-limit throttling

        return 0;
}


int writeToTag(int idToWrite)
{
        char tagBase[12]="";

        //we are only ever changing the last byte of the tag ID, so fill first 11 bytes as 0
        sprintf(tagBase,"%c%c%c%c%c%c%c%c%c%c%c%c",(char)0,(char)0,(char)0,(char)0,(char)0,(char)0,(char)0,(char)0,(char)0,(char)0,(char)0,(char)idToWrite);

        byte responseType = nano.writeTagEPC(tagBase, 12);

        if (responseType == RESPONSE_SUCCESS)
                return 1;
        else
                return 0;
}

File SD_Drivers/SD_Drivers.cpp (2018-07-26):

#include "SD_Drivers.h"



/**
 * Function: initializeSDCard()
 *------------------
 * Initializes SD card communication and data file.
 *
 * Return: 1: if SD card is present and file created successfully
 *         0: SD card cannot intialize properly
 */
int initializeSDCard()
{
        NeoSerial.print("Initializing SD card...");

        if (!SD.begin(SD_CARD_SLAVE_SELECT_PIN))
        {
                NeoSerial.println("initialization failed!");
                return 1;
        }
        NeoSerial.println("initialization done.");

        if (SD.exists("Data.csv"))
        {
                NeoSerial.println("Data.csv exists.");
        }
        else
        {
                NeoSerial.println("Data.csv doesn't exist.");
                NeoSerial.println("Creating data.csv...");
                myFile = SD.open("Data.csv", FILE_WRITE);
                myFile.println("Tag ID,Date,Time,Latitude,Longitude");
                myFile.close();
        }

// open a new file and immediately close it:


// Check to see if the file exists:
        if (SD.exists("Data.csv"))
        {
                NeoSerial.println("Data.csv exists.");
        } else
        {
                NeoSerial.println("Data.csv doesn't exist.");
        }

        return 0;
}

/**
 * Function: logDetectionEvent(String idNum, String timeStamp, String GPSCoords)
 *------------------
 * Creates string from data passed in and logs to SD card.
 *
 * idNum: Turtle ID returned from RFID tag
 * timeStamp: GPS timestamp of detection event
 * GPSCoords: GPS coordinates of detection event
 *
 * Return: 1: if data written successfully
 *         0: if data not logged successfully
 */
int logDetectionEvent(char idNum[], char timeS[], char dateS[], long Lat, long Long)
{

        File detectionData;
        // make a string for assembling the data to log:
        int make_room_at_lat = 2;
        int make_room_at_long = 3;
        int room_to_make = 1;
        char dataString[120];
        char longStr[15];
        char latStr[15];

//if our dummy data values were passed in, replace with "N/A"
        if (Lat != 1234567 && Long !=1234567)
        {

                //Lat and long are passed in as longs in order to keep 7 digits of precision
                ltoa(Lat,latStr,10);
                ltoa(Long,longStr,10);

//need to place decimal points in long and lat strings
                memmove(
                        longStr + make_room_at_long + room_to_make,
                        longStr + make_room_at_long,
                        15 - (make_room_at_long + room_to_make)
                        );
                longStr[make_room_at_long] = '.';


                memmove(
                        latStr + make_room_at_lat + room_to_make,
                        latStr + make_room_at_lat,
                        15 - (make_room_at_lat + room_to_make)
                        );
                latStr[make_room_at_lat] = '.';



                sprintf(dataString,"%s,%s,%s,%s,%s",idNum,dateS,timeS,latStr,longStr);
        }
        else
        {
                sprintf(dataString,"%s,%s,%s,%s,%s",idNum,dateS,timeS,"N/A","N/A");
        }
        //open file
        detectionData = SD.open("Data.csv", FILE_WRITE);
        if (detectionData)
        {
                //write to and close file
                detectionData.println(dataString);
                detectionData.close();
                return 1;
        }
        else
        {
                NeoSerial.println("Error writing to file !");
                return 0;
        }
}

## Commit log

2018-05-02 Added main file with libraries
    -User must have the included libraries in their Arduino IDE's libraries.
2018-06-10 Added sample RTC code
2018-06-16 Adding Libraries
    //--------------NeoGPS-----------------
    -Library to parse and organize GPS receiver data
    //-----------NeoHWSerial--------------
    -Library required in order to run NeoGPS parsing with interrupts
    //---------------SD----------------------
    -Built in Arduino Library for reading and writing to SD cards
    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
2018-06-17 Adding SD card drivers
2018-06-27 Adding RFID Drivers, Update LCD Lib, Add logic to main
    -Added lots of code in main that needs to be tested.
    -Ctrl-f "TODO" to see what logic still needs to be added
2018-06-30 Added voltage reader implementation
2018-06-30 Adding code to main, updating a couple libraries
2018-07-02 Added changes to main logic
    -added waiting state while we get GPS fix
    -made sure we only started RFID reading one time each time we wnter the main state
    [RFID_Drivers.cpp, main.ino]
2018-07-03 Adding basic duplicate tag checking, and modify battery display
2018-07-03 Added buzzer functionality and edited battery percentage status calls
    [VoltageReader.cpp, main.ino]
2018-07-07 Modified libraries and main after initial debugging
    -Debuged logging to SD card
    -Displaying correctly on screen
    -seamlessly changing in between detection and main screen
    -waiting for GPS fix
    -duplication detection
    Still need to debug:
    -battery/charge
    -actual RFID reader
    -pulling out tagID with new method
    -buzzer
2018-07-09 Implmented 10s button press timeout
2018-07-09 Added error code screens for bad SD and RFID initialization
    [RFID_Drivers.cpp, SD_Drivers.cpp, main.ino]
2018-07-12 Fixed buzzer functionality for new PCB layout, added KP theme buzz
2018-07-16 Adding 3d prints of parts
    [ArmRest_Adpt.STL, Battery Holder Size Reducer.STL, Bracket_CASE_COVER.STL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]
2018-07-16 Fixing battery charge updating. Setting buzzer frequency lower
    [VoltageReader.cpp, main.ino]
2018-07-16 Added voltage reader documentation.
2018-07-20 Adding battery checks as well as GPS timeouts
2018-07-20 Added blinking LED green every 2 seconds in main state
2018-07-23 Added gps fix exit option.
    [main.ino]
2018-07-24 Updating LED and LCD library
2018-07-24 Implemented button select on basic mode detection screen, no button select timeouts on detection screens.
2018-07-24 Changed voltage reading return value from percantage to minutes.
2018-07-24 Adding low battery checks
2018-07-24 Modifying button timeouts
2018-07-25 Fixed button selection, and LCD instruction screen portions
    [VoltageReader.cpp, main.ino]
2018-07-25 Adding RFID drivers for flashing tag ID
